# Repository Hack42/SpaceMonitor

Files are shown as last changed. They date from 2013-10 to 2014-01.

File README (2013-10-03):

SpaceMonitor controller

Dit project heeft als doel het beter bewaken van de ruimtes in de space. Momenteel wordt de temperatuur gemonitord, en wordt bewaakt of van een aantal ruimtes de ramen gesloten zijn als de SpaceState uit staat.

Het project voorziet in een controller per ruimte, die serieel communiceert met een centraal systeem. Deze controller is gebaseerd op een ATMEGA88 of 168, en is voorzien van 
* 12 I/O poorten (waarvan maximaal 4 als analoge ingang geschakeld kunnen worden)
* 2 open-collector uitgangen, max. 35V 1A
* een Dallas 18B20 voor temperatuurmeting
* optioneel een MAX232 voor de seriele verbinding, wanneer TTL-nivo RS232 niet voldoet

Ramen en deuren kunnen via microswitches verbonden worden met elk een I/O poort. De overige poorten kunnen gebruikt worden voor andere signaalgevers, of om apparatuur aan te sturen. De OC-uitgangen kunnen gebruikt worden om bijvoorbeeld een sirene of een flitslamp te schakelen

https://hack42.nl/wiki/Space_monitoring

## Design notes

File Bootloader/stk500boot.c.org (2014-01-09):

/*****************************************************************************
Title:     STK500v2 compatible bootloader
Author:    Peter Fleury <pfleury@gmx.ch>   http://jump.to/fleury
File:      $Id: stk500boot.c,v 1.15 2008/05/25 09:09:30 peter Exp $
Compiler:  avr-gcc 4.x / avr-libc 1.4.x 
Hardware:  All AVRs with bootloader support, tested with ATmega8
License:   GNU General Public License 
          
DESCRIPTION:
    This program allows an AVR with bootloader capabilities to 
    read/write its own Flash/EEprom. To enter Programming mode   
    an input pin is checked. If this pin is pulled low, programming mode  
    is entered. If not, normal execution is done from $0000 
    "reset" vector in Application area.
    Size < 500 words, fits into a 512 word bootloader section 
	when compiled with avr-gcc 4.1
   
USAGE:
    - Set AVR MCU type and clock-frequency (F_CPU) in the Makefile.
    - Set baud rate below (AVRISP only works with 115200 bps)
    - compile/link the bootloader with the supplied Makefile
    - program the "Boot Flash section size" (BOOTSZ fuses),
      for boot-size 512 words:  program BOOTSZ1
    - enable the BOOT Reset Vector (program BOOTRST)
    - Upload the hex file to the AVR using any ISP programmer
    - Program Boot Lock Mode 3 (program BootLock 11 and BootLock 12 lock bits)
    - Reset your AVR while keeping PROG_PIN pulled low
    - Start AVRISP Programmer (AVRStudio/Tools/Program AVR)
    - AVRISP will detect the bootloader
    - Program your application FLASH file and optional EEPROM file using AVRISP
    
Note: 
    Erasing the device without flashing, through AVRISP GUI button "Erase Device" 
    is not implemented, due to AVRStudio limitations.
    Flash is always erased before programming.
    
    Normally the bootloader accepts further commands after programming. 
    The bootloader exits and starts applicaton code after programming 
    when ENABLE_LEAVE_BOOTLADER is defined.
    Use Auto Programming mode to programm both flash and eeprom, 
    otherwise bootloader will exit after flash programming.
    
	AVRdude:
	Please uncomment #define REMOVE_CMD_SPI_MULTI when using AVRdude.
	Comment #define REMOVE_PROGRAM_LOCK_BIT_SUPPORT to reduce code size
	Read Fuse Bits and Read/Write Lock Bits is not supported

NOTES:
    Based on Atmel Application Note AVR109 - Self-programming
    Based on Atmel Application Note AVR068 - STK500v2 Protocol    
          
LICENSE:
    Copyright (C) 2006 Peter Fleury

    This program is free software; you can redistribute it and/or modify
    it under the terms of the GNU General Public License as published by
    the Free Software Foundation; either version 2 of the License, or
    any later version.

    This program is distributed in the hope that it will be useful,
    but WITHOUT ANY WARRANTY; without even the implied warranty of
    MERCHANTABILITY or FITNESS FOR A PARTICULAR PURPOSE.  See the
    GNU General Public License for more details.

*****************************************************************************/
#include <inttypes.h>
#include <avr/io.h>
#include <avr/interrupt.h>
#include <avr/boot.h>
#include <avr/pgmspace.h>
#include "command.h"

/*
 * Uncomment the following lines to save code space 
 */
//#define REMOVE_PROGRAM_LOCK_BIT_SUPPORT  // disable program lock bits
//#define REMOVE_BOOTLOADER_LED            // no LED to show active bootloader
//#define REMOVE_PROG_PIN_PULLUP           // disable internal pullup, use external 
#define REMOVE_CMD_SPI_MULTI             // disable processing of SPI_MULTI commands

/*
 *  Uncomment to leave bootloader and jump to application after programming.
 */
//#define ENABLE_LEAVE_BOOTLADER           

/* 
 * Pin "PROG_PIN" on port "PROG_PORT" has to be pulled low
 * (active low) to start the bootloader 
 * uncomment #define REMOVE_PROG_PIN_PULLUP if using an external pullup
 */
#define PROG_PORT  PORTD
#define PROG_DDR   DDRD
#define PROG_IN    PIND
#define PROG_PIN   PIND2

/*
 * Active-low LED on pin "PROGLED_PIN" on port "PROGLED_PORT" 
 * indicates that bootloader is active
 */
#define PROGLED_PORT PORTB
#define PROGLED_DDR  DDRB
#define PROGLED_PIN  PINB1

/*
 * define CPU frequency in Mhz here if not defined in Makefile 
 */
#ifndef F_CPU
#define F_CPU 7372800UL
#endif

/*
 * define which UART channel will be used, if device with two UARTs is used
 */
//#define USE_USART1        // undefined means use USART0

/*
 * UART Baudrate, AVRStudio AVRISP only accepts 115200 bps
 */
#define BAUDRATE 115200

/*
 *  Enable (1) or disable (0) USART double speed operation
 */
#define UART_BAUDRATE_DOUBLE_SPEED 0

/*
 * HW and SW version, reported to AVRISP, must match version of AVRStudio
 */
#define CONFIG_PARAM_BUILD_NUMBER_LOW	0
#define CONFIG_PARAM_BUILD_NUMBER_HIGH	0
#define CONFIG_PARAM_HW_VER				0x0F
#define CONFIG_PARAM_SW_MAJOR			2
#define CONFIG_PARAM_SW_MINOR			0x0A

/*
 * Calculate the address where the bootloader starts from FLASHEND and BOOTSIZE
 * (adjust BOOTSIZE below and BOOTLOADER_ADDRESS in Makefile if you want to change the size of the bootloader)
 */
#define BOOTSIZE 512
#define APP_END  (FLASHEND -(2*BOOTSIZE) + 1)

/*
 * Signature bytes are not available in avr-gcc io_xxx.h
 */
#if defined (__AVR_ATmega8__)
    #define SIGNATURE_BYTES 0x1E9307
#elif defined (__AVR_ATmega16__)
    #define SIGNATURE_BYTES 0x1E9403
#elif defined (__AVR_ATmega32__)
    #define SIGNATURE_BYTES 0x1E9502
#elif defined (__AVR_ATmega8515__)
    #define SIGNATURE_BYTES 0x1E9306
#elif defined (__AVR_ATmega8535__)
    #define SIGNATURE_BYTES 0x1E9308
#elif defined (__AVR_ATmega88__)
    #define SIGNATURE_BYTES 0x1E930A
#elif defined (__AVR_ATmega162__)
    #define SIGNATURE_BYTES 0x1E9404
#elif defined (__AVR_ATmega168__)
    #define SIGNATURE_BYTES 0x1E9406
#elif defined (__AVR_ATmega128__)
    #define SIGNATURE_BYTES 0x1E9702
#elif defined (__AVR_AT90CAN32__)
	#define SIGNATURE_BYTES 0x1E9581
#elif defined (__AVR_AT90CAN64__)
	#define SIGNATURE_BYTES 0x1E9681
#elif defined (__AVR_AT90CAN128__)
	#define SIGNATURE_BYTES 0x1E9781    
#else
	#error "no signature definition for MCU available"
#endif

/*
 *  Defines for the various USART registers
 */
#if  defined(__AVR_ATmega8__)    || defined(__AVR_ATmega16__) || defined(__AVR_ATmega32__) \
  || defined(__AVR_ATmega8515__) || defined(__AVR_ATmega8535__) 
/* 
 * ATMega with one USART
 */ 
#define	UART_BAUD_RATE_LOW	     UBRRL
#define	UART_STATUS_REG	         UCSRA
#define	UART_CONTROL_REG	     UCSRB
#define	UART_ENABLE_TRANSMITTER	 TXEN
#define	UART_ENABLE_RECEIVER	 RXEN
#define	UART_TRANSMIT_COMPLETE	 TXC
#define	UART_RECEIVE_COMPLETE	 RXC
#define	UART_DATA_REG	         UDR
#define UART_DOUBLE_SPEED        U2X

#elif  defined(__AVR_ATmega64__) || defined(__AVR_ATmega128__) || defined(__AVR_ATmega162__) || defined(__AVR_ATmega88__) || defined(__AVR_ATmega168__) \
	|| defined(__AVR_AT90CAN32__) || defined(__AVR_AT90CAN64__) || defined(__AVR_AT90CAN128__)
/* 
 *  ATMega with two USART, select USART for bootloader using USE_USART1 define
 */ 
#ifndef USE_USART1

#define	UART_BAUD_RATE_LOW	     UBRR0L
#ifdef UBRR0H
#define UART_BAUD_RATE_HIGH	     UBRR0H
#endif
#define	UART_STATUS_REG	         UCSR0A
#define	UART_CONTROL_REG	     UCSR0B
#define	UART_ENABLE_TRANSMITTER	 TXEN0
#define	UART_ENABLE_RECEIVER	 RXEN0
#define	UART_TRANSMIT_COMPLETE	 TXC0
#define	UART_RECEIVE_COMPLETE	 RXC0
#define	UART_DATA_REG	         UDR0
#define UART_DOUBLE_SPEED        U2X0

#else

#define	UART_BAUD_RATE_LOW	     UBRR1L
#ifdef UBRR1H
#define UART_BAUD_RATE_HIGH      UBRR1H
#endif
#define	UART_STATUS_REG	         UCSR1A
#define	UART_CONTROL_REG	     UCSR1B
#define	UART_ENABLE_TRANSMITTER	 TXEN1
#define	UART_ENABLE_RECEIVER	 RXEN1
#define	UART_TRANSMIT_COMPLETE	 TXC1
#define	UART_RECEIVE_COMPLETE	 RXC1
#define	UART_DATA_REG	         UDR1
#define UART_DOUBLE_SPEED        U2X1

#endif

#else
	#error "no UART definition for MCU available"
#endif

/*
 * Macros to map the new ATmega88/168 EEPROM bits
 */
#ifdef EEMPE        				        		            
#define EEMWE EEMPE
#define EEWE  EEPE
#endif

/*
 * Macro to calculate UBBR from XTAL and baudrate
 */
#if UART_BAUDRATE_DOUBLE_SPEED
#define UART_BAUD_SELECT(baudRate,xtalCpu) (((float)(xtalCpu))/(((float)(baudRate))*8.0)-1.0+0.5)
#else
#define UART_BAUD_SELECT(baudRate,xtalCpu) (((float)(xtalCpu))/(((float)(baudRate))*16.0)-1.0+0.5)
#endif

/*
 * States used in the receive state machine
 */
#define	ST_START		0
#define	ST_GET_SEQ_NUM	1
#define ST_MSG_SIZE_1	2
#define ST_MSG_SIZE_2	3
#define ST_GET_TOKEN	4
#define ST_GET_DATA		5
#define	ST_GET_CHECK	6
#define	ST_PROCESS		7

/*
 * use 16bit address variable for ATmegas with <= 64K flash
 */
#if defined(RAMPZ)
typedef uint32_t address_t;
#else
typedef uint16_t address_t;
#endif

/*
 * function prototypes
 */ 
static void sendchar(char c);
static unsigned char recchar(void);

/*
 * since this bootloader is not linked against the avr-gcc crt1 functions,
 * to reduce the code size, we need to provide our own initialization
 */
void __jumpMain     (void) __attribute__ ((naked)) __attribute__ ((section (".init9")));

void __jumpMain(void)
{    
    asm volatile ( ".set __stack, %0" :: "i" (RAMEND) );
    
    /* init stack here, bug WinAVR 20071221 does not init stack based on __stack */  
    asm volatile ("ldi r24,%0":: "M" (RAMEND & 0xFF));          
    asm volatile ("ldi r25,%0":: "M" (RAMEND >> 8));
    asm volatile ("out __SP_H__,r25" ::);
    asm volatile ("out __SP_L__,r24" ::);
    
    asm volatile ( "clr __zero_reg__" );                       // GCC depends on register r1 set to 0
    asm volatile ( "out %0, __zero_reg__" :: "I" (_SFR_IO_ADDR(SREG)) );  // set SREG to 0
#ifndef REMOVE_PROG_PIN_PULLUP	 
	PROG_PORT |= (1<<PROG_PIN);		                           // Enable internal pullup
#endif    
    asm volatile ( "rjmp main");                               // jump to main()
}

/*
 * send single byte to USART, wait until transmission is completed
 */
static void sendchar(char c)
{
    UART_DATA_REG = c;                                         // prepare transmission
    while (!(UART_STATUS_REG & (1 << UART_TRANSMIT_COMPLETE)));// wait until byte sent
    UART_STATUS_REG |= (1 << UART_TRANSMIT_COMPLETE);          // delete TXCflag
}

/*
 * Read single byte from USART, block if no data available
 */
static unsigned char recchar(void)
{
    while(!(UART_STATUS_REG & (1 << UART_RECEIVE_COMPLETE)));  // wait for data
    return UART_DATA_REG;
}

int main(void) __attribute__ ((OS_main));
int main(void)
{
    address_t       address = 0;
    address_t       eraseAddress = 0;	
	unsigned char   msgParseState;
    unsigned int    i = 0;
    unsigned char   checksum = 0;
    unsigned char   seqNum = 0;
    unsigned int    msgLength = 0;
    unsigned char   msgBuffer[285];
    unsigned char   c, *p;
    unsigned char   isLeave = 0;

	/*
	 * Branch to bootloader or application code ?
	 */	
	if(!(PROG_IN & (1<<PROG_PIN)))  
	{ 	    
#ifndef REMOVE_BOOTLOADER_LED
        /* PROG_PIN pulled low, indicate with LED that bootloader is active */
        PROGLED_DDR  |= (1<<PROGLED_PIN);
        PROGLED_PORT &= ~(1<<PROGLED_PIN);
#endif
        /*
         * Init UART
         * set baudrate and enable USART receiver and transmiter without interrupts 
         */     
#if UART_BAUDRATE_DOUBLE_SPEED
        UART_STATUS_REG   |=  (1 <<UART_DOUBLE_SPEED);
#endif
  
#ifdef UART_BAUD_RATE_HIGH    
        UART_BAUD_RATE_HIGH = 0;     
#endif       
        UART_BAUD_RATE_LOW = UART_BAUD_SELECT(BAUDRATE,F_CPU);
        UART_CONTROL_REG   = (1 << UART_ENABLE_RECEIVER) | (1 << UART_ENABLE_TRANSMITTER); 

        /* main loop */
        while(!isLeave)                             
        {   
            /*
             * Collect received bytes to a complete message
             */            
            msgParseState = ST_START;
	        while ( msgParseState != ST_PROCESS )
	        {
           		c = recchar();
                switch (msgParseState)
                {
                case ST_START:
				    if( c == MESSAGE_START )
				    {
					    msgParseState = ST_GET_SEQ_NUM;
					    checksum = MESSAGE_START^0;
				    }
				    break;
				    
				case ST_GET_SEQ_NUM:
                    if ( (c == 1) || (c == seqNum) )
                    {
				        seqNum = c;
				        msgParseState = ST_MSG_SIZE_1;
				        checksum ^= c;
                    }
                    else
                    {
                        msgParseState = ST_START;
                    }
			        break;
			        
			    case ST_MSG_SIZE_1:			    
				    msgLength = (unsigned int)c<<8;
				    msgParseState = ST_MSG_SIZE_2;
				    checksum ^= c;
				    break;
				    
			    case ST_MSG_SIZE_2:			
				    msgLength |= c;
				    msgParseState = ST_GET_TOKEN;
				    checksum ^= c;
				    break;
			    
			    case ST_GET_TOKEN:
			        if ( c == TOKEN )
				    {
					    msgParseState = ST_GET_DATA;
					    checksum ^= c;
					    i = 0;
				    }
				    else
				    {
				        msgParseState = ST_START;
				    }
				    break;
			    
			    case ST_GET_DATA:			        
				    msgBuffer[i++] = c;
				    checksum ^= c;
				    if ( i == msgLength )
				    {
					    msgParseState = ST_GET_CHECK;
				    }
				    break;
						
			    case ST_GET_CHECK:
				    if( c == checksum )
				    {
					    msgParseState = ST_PROCESS;					    
				    }
				    else
				    {
				        msgParseState = ST_START;
				    }
				    break;
				}//switch
			}//while(msgParseState)
			
			/*
			 * Now process the STK500 commands, see Atmel Appnote AVR068
			 */
			
	        switch (msgBuffer[0])
	        {
#ifndef REMOVE_CMD_SPI_MULTI
			case CMD_SPI_MULTI:
				{
	                unsigned char answerByte = 0;

                    // only Read Signature Bytes implemented, return dummy value for other instructions
					if ( msgBuffer[4]== 0x30 )
					{						
						unsigned char signatureIndex = msgBuffer[6];						

						if ( signatureIndex == 0 )
							answerByte = (SIGNATURE_BYTES >>16) & 0x000000FF;
						else if ( signatureIndex == 1 )
							answerByte = (SIGNATURE_BYTES >> 8) & 0x000000FF;
						else
							answerByte = SIGNATURE_BYTES & 0x000000FF;
					}					
    				msgLength = 7;
					msgBuffer[1] = STATUS_CMD_OK;
					msgBuffer[2] = 0;					
					msgBuffer[3] = msgBuffer[4];  // Instruction Byte 1
					msgBuffer[4] = msgBuffer[5];  // Instruction Byte 2
					msgBuffer[5] = answerByte;	                
					msgBuffer[6] = STATUS_CMD_OK;
				}
				break;
#endif
            case CMD_SIGN_ON:
		        msgLength = 11;		        
		        msgBuffer[1]  = STATUS_CMD_OK;
		        msgBuffer[2]  = 8;
		        msgBuffer[3]  = 'A';
		        msgBuffer[4]  = 'V';
		        msgBuffer[5]  = 'R';
		        msgBuffer[6]  = 'I';
		        msgBuffer[7]  = 'S';
		        msgBuffer[8]  = 'P';
		        msgBuffer[9]  = '_';
		        msgBuffer[10] = '2';
		        break;
	        
	        case CMD_GET_PARAMETER:
	            {
	                unsigned char value;
	                
    		        switch(msgBuffer[1])
    		        {
    			    case PARAM_BUILD_NUMBER_LOW:
    				    value = CONFIG_PARAM_BUILD_NUMBER_LOW;
    				    break;				    
    			    case PARAM_BUILD_NUMBER_HIGH:
    				    value = CONFIG_PARAM_BUILD_NUMBER_HIGH;
    				    break;				    
    			    case PARAM_HW_VER:
    				    value = CONFIG_PARAM_HW_VER;
    				    break;				    
    			    case PARAM_SW_MAJOR:
    				    value = CONFIG_PARAM_SW_MAJOR;
    				    break;
    			    case PARAM_SW_MINOR:
    				    value = CONFIG_PARAM_SW_MINOR;
    				    break;				
    				default:
    				    value = 0;
    				    break;
    		        }
		            msgLength = 3;		        
		            msgBuffer[1] = STATUS_CMD_OK;
		            msgBuffer[2] = value;
		        }
	            break;
	            
	        case CMD_LEAVE_PROGMODE_ISP:
#ifdef ENABLE_LEAVE_BOOTLADER
	            isLeave = 1;
#endif
	        case CMD_ENTER_PROGMODE_ISP:    	            
	        case CMD_SET_PARAMETER:	        
		        msgLength = 2;		        
		        msgBuffer[1] = STATUS_CMD_OK;
                break;

            case CMD_READ_SIGNATURE_ISP:
                {
                    unsigned char signatureIndex = msgBuffer[4];
                    unsigned char signature;

                    if ( signatureIndex == 0 )
                        signature = (SIGNATURE_BYTES >>16) & 0x000000FF;
                    else if ( signatureIndex == 1 )
                        signature = (SIGNATURE_BYTES >> 8) & 0x000000FF;
                    else
                        signature = SIGNATURE_BYTES & 0x000000FF;

	                msgLength = 4;
	                msgBuffer[1] = STATUS_CMD_OK;
	                msgBuffer[2] = signature;
	                msgBuffer[3] = STATUS_CMD_OK;	                
	            }
                break;

            case CMD_READ_LOCK_ISP:            
                msgLength = 4;
	            msgBuffer[1] = STATUS_CMD_OK;
	            msgBuffer[2] = boot_lock_fuse_bits_get( GET_LOCK_BITS );
	            msgBuffer[3] = STATUS_CMD_OK;	                                                
                break;
            
            case CMD_READ_FUSE_ISP:
                {                    
                    unsigned char fuseBits;                    
                    
                    if ( msgBuffer[2] == 0x50 )
                    {
                        if ( msgBuffer[3] == 0x08 )
                            fuseBits = boot_lock_fuse_bits_get( GET_EXTENDED_FUSE_BITS );                            
                        else
                            fuseBits = boot_lock_fuse_bits_get( GET_LOW_FUSE_BITS );                            
                    }
                    else 
                    {
                        fuseBits = boot_lock_fuse_bits_get( GET_HIGH_FUSE_BITS );
                    }                    
                    msgLength = 4;    
	                msgBuffer[1] = STATUS_CMD_OK;
	                msgBuffer[2] = fuseBits;	                
	                msgBuffer[3] = STATUS_CMD_OK;	                                    
                }
                break;
                
#ifndef REMOVE_PROGRAM_LOCK_BIT_SUPPORT
            case CMD_PROGRAM_LOCK_ISP:
                {
                    unsigned char lockBits = msgBuffer[4];
                    
                    lockBits = (~lockBits) & 0x3C;  // mask BLBxx bits
				    boot_lock_bits_set(lockBits);	// and program it
				    boot_spm_busy_wait();
                    
                    msgLength = 3;
	                msgBuffer[1] = STATUS_CMD_OK;	                
	                msgBuffer[2] = STATUS_CMD_OK;	                                                        
                }
                break;
#endif
            case CMD_CHIP_ERASE_ISP:
                eraseAddress = 0;
	            msgLength = 2;
	            msgBuffer[1] = STATUS_CMD_OK;
                break;

            case CMD_LOAD_ADDRESS:
#if defined(RAMPZ)
                address = ( ((address_t)(msgBuffer[1])<<24)|((address_t)(msgBuffer[2])<<16)|((address_t)(msgBuffer[3])<<8)|(msgBuffer[4]) )<<1;
#else
		        address = ( ((msgBuffer[3])<<8)|(msgBuffer[4]) )<<1;  //convert word to byte address
#endif
		        msgLength = 2;
		        msgBuffer[1] = STATUS_CMD_OK;
                break;
                
            case CMD_PROGRAM_FLASH_ISP:
            case CMD_PROGRAM_EEPROM_ISP:                
                {
                    unsigned int  size = (((unsigned int)msgBuffer[1])<<8) | msgBuffer[2];
                    unsigned char *p = msgBuffer+10;
                    unsigned int  data;
                    unsigned char highByte, lowByte;                    
                    address_t     tempaddress = address;

                    if ( msgBuffer[0] == CMD_PROGRAM_FLASH_ISP )
                    {
                		// erase only main section (bootloader protection)
                		if  (  eraseAddress < APP_END )
                		{
                			boot_page_erase(eraseAddress);	// Perform page erase
                			boot_spm_busy_wait();		// Wait until the memory is erased.
                			eraseAddress += SPM_PAGESIZE;    // point to next page to be erase
                		}
                        
    		            /* Write FLASH */
        		        do {
        		            lowByte   = *p++;
        		            highByte  = *p++;
        				    
        				    data =  (highByte << 8) | lowByte;
        				    boot_page_fill(address,data);
        											
        				    address = address + 2;  	// Select next word in memory
        				    size -= 2;			// Reduce number of bytes to write by two    
        			    } while(size);			// Loop until all bytes written
        			    
            			boot_page_write(tempaddress);
        	    		boot_spm_busy_wait();	
        		    	boot_rww_enable();				// Re-enable the RWW section                    
    		        }
    		        else
    		        {
    		            /* write EEPROM */
        			    do {
        	 	            EEARL = address;			// Setup EEPROM address
        	                EEARH = (address >> 8);
        				    address++;					// Select next EEPROM byte
        
        				    EEDR= *p++;				    // get byte from buffer
        	                EECR |= (1<<EEMWE);			// Write data into EEPROM
        	                EECR |= (1<<EEWE);
        	            
        				    while (EECR & (1<<EEWE));	// Wait for write operation to finish
        				    size--;						// Decrease number of bytes to write
        			    } while(size);					// Loop until all bytes written    		            
    		        }
           		    msgLength = 2;
		            msgBuffer[1] = STATUS_CMD_OK;    		        
                }
                break;
                
            case CMD_READ_FLASH_ISP:
            case CMD_READ_EEPROM_ISP:                                                
                {
                    unsigned int  size = (((unsigned int)msgBuffer[1])<<8) | msgBuffer[2];
                    unsigned char *p = msgBuffer+1;
                    msgLength = size+3;
                    
                    *p++ = STATUS_CMD_OK;                    
                    if (msgBuffer[0] == CMD_READ_FLASH_ISP )
                    {
                        unsigned int data;
                        
                        // Read FLASH
                        do {                            
#if defined(RAMPZ)
                			data = pgm_read_word_far(address);
#else
        		        	data = pgm_read_word_near(address);
#endif
        			        *p++ = (unsigned char)data;         //LSB
        			        *p++ = (unsigned char)(data >> 8);	//MSB  
        			        address    += 2;  	 // Select next word in memory
        			        size -= 2;
                        }while (size);
                    }
                    else
                    {
          			    /* Read EEPROM */
        			    do {
        			        EEARL = address;			// Setup EEPROM address
        			        EEARH = ((address >> 8));
        			        address++;					// Select next EEPROM byte
        			        EECR |= (1<<EERE);			// Read EEPROM
        			        *p++ = EEDR;				// Send EEPROM data
        			        size--;    			        
        		        }while(size);
                    }
                    *p++ = STATUS_CMD_OK;
                }
                break;

	        default:
	            msgLength = 2;   
	            msgBuffer[1] = STATUS_CMD_FAILED;
	            break;
	        }

            /*
             * Now send answer message back
             */
	        sendchar(MESSAGE_START);     
	        checksum = MESSAGE_START^0;
	        
	        sendchar(seqNum);
	        checksum ^= seqNum;
	        
	        c = ((msgLength>>8)&0xFF);
	        sendchar(c);
	        checksum ^= c;
	        
	        c = msgLength&0x00FF;
	        sendchar(c);
	        checksum ^= c;
	        
	        sendchar(TOKEN);
	        checksum ^= TOKEN;

            p = msgBuffer;
            while ( msgLength )
            {                
               c = *p++;
               sendchar(c);
               checksum ^=c;
               msgLength--;               
            }                   
	        sendchar(checksum);	        
	        seqNum++;

	    }//for

#ifndef REMOVE_BOOTLOADER_LED
        PROGLED_DDR  &= ~(1<<PROGLED_PIN);   // set to default     
#endif
    }
    
	/*
	 * Now leave bootloader
	 */
#ifndef REMOVE_PROG_PIN_PULLUP	
	PROG_PORT &= ~(1<<PROG_PIN);    // set to default
#endif	
	boot_rww_enable();              // enable application section
	
	// Jump to Reset vector in Application Section
	// (clear register, push this register to the stack twice = adress 0x0000/words, and return to this address) 
    asm volatile ( 
		"clr r1" "\n\t"
		"push r1" "\n\t"
        "push r1" "\n\t" 
        "ret"     "\n\t" 
    ::); 

     /*
     * Never return to stop GCC to generate exit return code
     * Actually we will never reach this point, but the compiler doesn't 
     * understand this
     */
    for(;;);
}

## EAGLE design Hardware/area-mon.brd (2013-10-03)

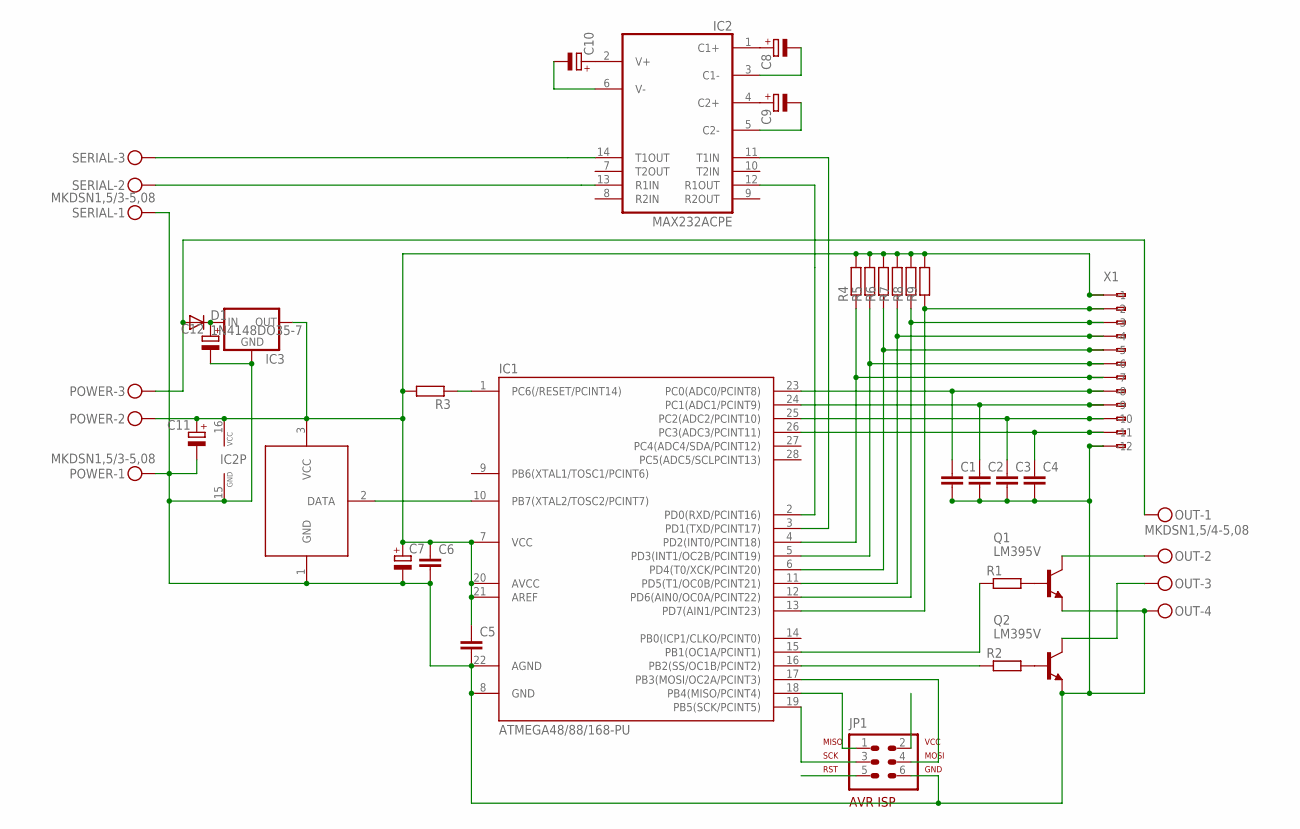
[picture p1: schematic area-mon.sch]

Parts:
C1, C2, C3, C4, C5, C6: C-EU050-024X044; C050-024X044
C7: CPOL-EUE5-8.5; E5-8,5
C8, C9, C10, C11, C12: CPOL-EUE2.5-5; E2,5-5
D1: 1N4148DO35-7; DO35-7
IC1: ATMEGA48/88/168-PU; DIL28-3
IC2: MAX232ACPE; DIL16
IC3: 78XXTO92L; TO92L
JP1: AVR-ISP-6VERT; AVR-ISP-6
OUT: MKDSN1,5/4-5,08
POWER: MKDSN1,5/3-5,08
Q1, Q2: LM395V; TO220V
R1, R2, R3, R4, R5, R6, R7, R8, R9: R-EU0207/10; 0207/10
SERIAL: MKDSN1,5/3-5,08
U$4: DS18B20; TO92-
X1: 233-512; MPN 0233-0512

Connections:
1WIRE: IC1.10 (PB7(XTAL2/TOSC2/PCINT7)), U$4.2 (DATA)
GND: C1.2, C2.2, C3.2, C4.2, C5.2, C6.2, C7.-, C11.-, C12.-, IC1.8 (GND), IC1.22 (AGND), IC2.15 (GND), IC3.2 (GND), JP1.6, OUT.4, POWER.1, Q1.C (E), Q2.C (E), SERIAL.1, U$4.1 (GND), X1.A12 (-12), X1.B12 (B-12)
MISO: IC1.18 (PB4(MISO/PCINT4)), JP1.1
MON-A-1: C1.1, IC1.23 (PC0(ADC0/PCINT8)), X1.A8 (-8), X1.B8 (B-8)
MON-A-2: C2.1, IC1.24 (PC1(ADC1/PCINT9)), X1.A9 (-9), X1.B9 (B-9)
MON-A-3: C3.1, IC1.25 (PC2(ADC2/PCINT10)), X1.A10 (-10), X1.B10 (B-10)
MON-A-4: C4.1, IC1.26 (PC3(ADC3/PCINT11)), X1.A11 (-11), X1.B11 (B-11)
MON-D-1: IC1.13 (PD7(AIN1/PCINT23)), R9.1, X1.A2 (-2), X1.B2 (B-2)
MON-D-2: IC1.12 (PD6(AIN0/OC0A/PCINT22)), R8.1, X1.A3 (-3), X1.B3 (B-3)
MON-D-3: IC1.11 (PD5(T1/OC0B/PCINT21)), R7.1, X1.A4 (-4), X1.B4 (B-4)
MON-D-4: IC1.6 (PD4(T0/XCK/PCINT20)), R6.1, X1.A5 (-5), X1.B5 (B-5)
MON-D-5: IC1.5 (PD3(INT1/OC2B/PCINT19)), R5.1, X1.A6 (-6), X1.B6 (B-6)
MON-D-6: IC1.4 (PD2(INT0/PCINT18)), R4.1, X1.A7 (-7), X1.B7 (B-7)
MOSI: IC1.17 (PB3(MOSI/OC2A/PCINT3)), JP1.4
unnamed: Q1.B, R1.2
unnamed: Q2.B, R2.2
unnamed: D1.A, OUT.1, POWER.3
unnamed: OUT.2, Q1.E (C)
unnamed: OUT.3, Q2.E (C)
unnamed: C8.+, IC2.1 (C1+)
unnamed: C9.+, IC2.4 (C2+)
unnamed: C9.-, IC2.5 (C2-)
unnamed: C8.-, IC2.3 (C1-)
unnamed: C10.+, IC2.2 (V+)
unnamed: C10.-, IC2.6 (V-)
unnamed: C12.+, D1.C, IC3.1 (IN)
OUT-CH-1: IC1.15 (PB1(OC1A/PCINT1)), R1.1
OUT-CH-2: IC1.16 (PB2(SS/OC1B/PCINT2)), R2.1
RST: IC1.1 (PC6(/RESET/PCINT14)), JP1.5, R3.1
RX-232: IC2.13 (R1IN), SERIAL.2
RXD: IC1.2 (PD0(RXD/PCINT16)), IC2.12 (R1OUT)
SCK: IC1.19 (PB5(SCK/PCINT5)), JP1.3
TX-232: IC2.14 (T1OUT), SERIAL.3
TXD: IC1.3 (PD1(TXD/PCINT17)), IC2.11 (T1IN)
VCC: C5.1, C6.1, C7.+, C11.+, IC1.7 (VCC), IC1.20 (AVCC), IC1.21 (AREF), IC2.16 (VCC), IC3.3 (OUT), JP1.2, POWER.2, R3.2, R4.2, R5.2, R6.2, R7.2, R8.2, R9.2, U$4.3 (VCC), X1.A1 (-1), X1.B1 (B-1)

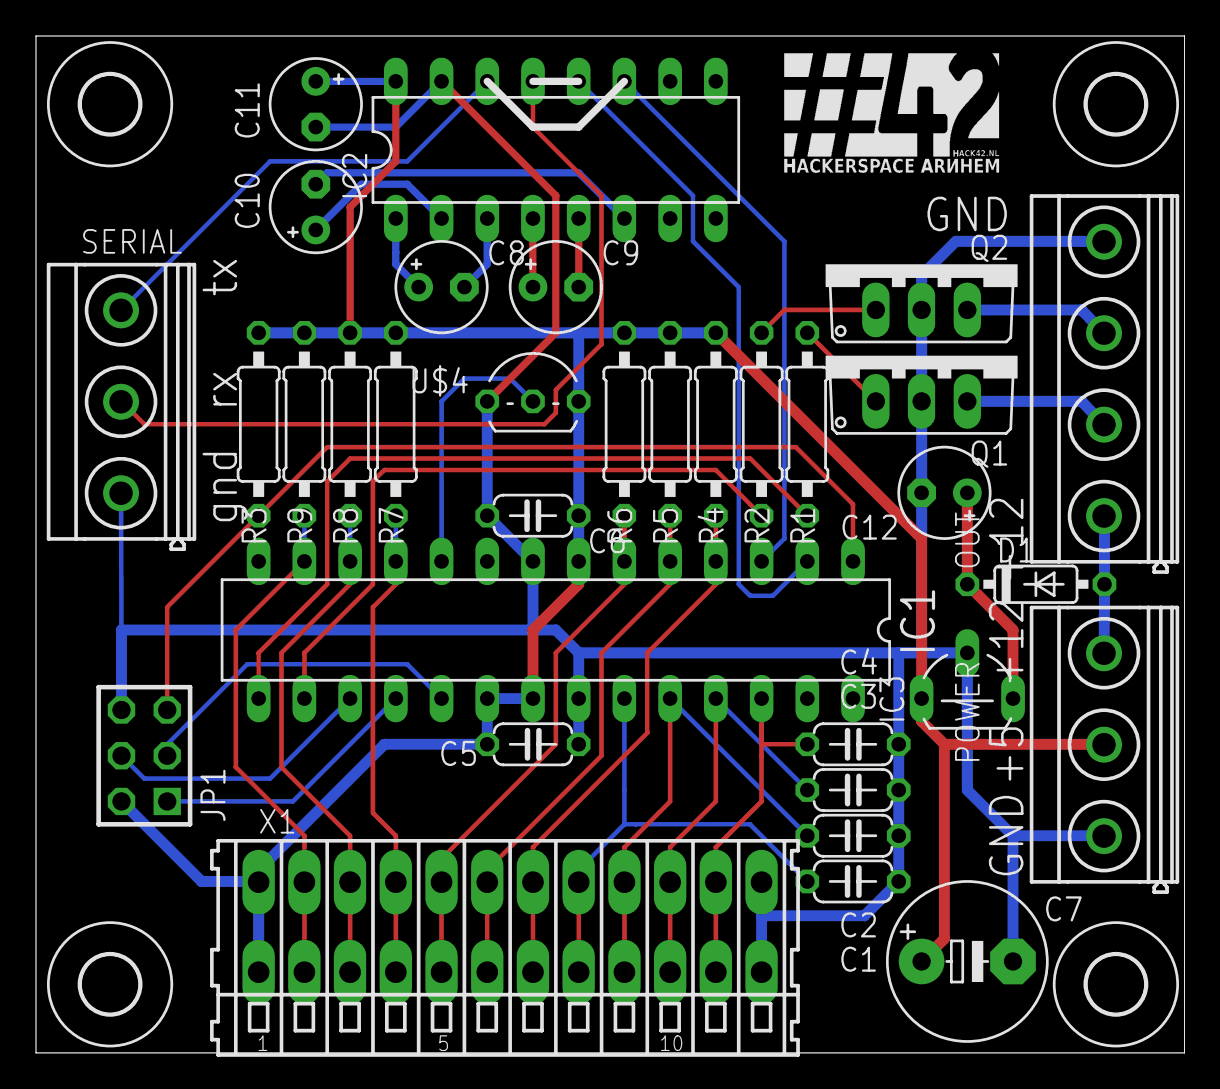
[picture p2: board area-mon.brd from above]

Board: 2 copper layers, 63.8 x 56.5 mm, 38 parts (0 on the bottom side), 35 nets.

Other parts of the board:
U$1, U$2, U$3, U$5: 3,2
U$6: LOGO_HACK42-12X7

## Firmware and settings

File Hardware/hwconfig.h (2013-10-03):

#ifndef HWCONFIG_H
#define HWCONFIG_H

//-----------------------------------------------------------------
//------------------------- DO NOT MODIFY -------------------------
//------------------Generated with the generate_hearer.ulp---------
//-----------------------------------------------------------------


#define 1WIRE_PORT   PORTB
#define 1WIRE_PINREG PINB
#define 1WIRE_PIN    7
#define 1WIRE_DDR    DDRB
#define 1WIRE        B,7

#define MISO_PORT   PORTB
#define MISO_PINREG PINB
#define MISO_PIN    4
#define MISO_DDR    DDRB
#define MISO        B,4

#define MON-A-1_PORT   PORTC
#define MON-A-1_PINREG PINC
#define MON-A-1_PIN    0
#define MON-A-1_DDR    DDRC
#define MON-A-1        C,0

#define MON-A-2_PORT   PORTC
#define MON-A-2_PINREG PINC
#define MON-A-2_PIN    1
#define MON-A-2_DDR    DDRC
#define MON-A-2        C,1

#define MON-A-3_PORT   PORTC
#define MON-A-3_PINREG PINC
#define MON-A-3_PIN    2
#define MON-A-3_DDR    DDRC
#define MON-A-3        C,2

#define MON-A-4_PORT   PORTC
#define MON-A-4_PINREG PINC
#define MON-A-4_PIN    3
#define MON-A-4_DDR    DDRC
#define MON-A-4        C,3

#define MON-D-1_PORT   PORTD
#define MON-D-1_PINREG PIND
#define MON-D-1_PIN    7
#define MON-D-1_DDR    DDRD
#define MON-D-1        D,7

#define MON-D-2_PORT   PORTD
#define MON-D-2_PINREG PIND
#define MON-D-2_PIN    6
#define MON-D-2_DDR    DDRD
#define MON-D-2        D,6

#define MON-D-3_PORT   PORTD
#define MON-D-3_PINREG PIND
#define MON-D-3_PIN    5
#define MON-D-3_DDR    DDRD
#define MON-D-3        D,5

#define MON-D-4_PORT   PORTD
#define MON-D-4_PINREG PIND
#define MON-D-4_PIN    4
#define MON-D-4_DDR    DDRD
#define MON-D-4        D,4

#define MON-D-5_PORT   PORTD
#define MON-D-5_PINREG PIND
#define MON-D-5_PIN    3
#define MON-D-5_DDR    DDRD
#define MON-D-5        D,3

#define MON-D-6_PORT   PORTD
#define MON-D-6_PINREG PIND
#define MON-D-6_PIN    2
#define MON-D-6_DDR    DDRD
#define MON-D-6        D,2

#define MOSI_PORT   PORTB
#define MOSI_PINREG PINB
#define MOSI_PIN    3
#define MOSI_DDR    DDRB
#define MOSI        B,3

#define OUT-CH-1_PORT   PORTB
#define OUT-CH-1_PINREG PINB
#define OUT-CH-1_PIN    1
#define OUT-CH-1_DDR    DDRB
#define OUT-CH-1        B,1

#define OUT-CH-2_PORT   PORTB
#define OUT-CH-2_PINREG PINB
#define OUT-CH-2_PIN    2
#define OUT-CH-2_DDR    DDRB
#define OUT-CH-2        B,2

#define RST_PORT   PORTC
#define RST_PINREG PINC
#define RST_PIN    6
#define RST_DDR    DDRC
#define RST        C,6

#define RXD_PORT   PORTD
#define RXD_PINREG PIND
#define RXD_PIN    0
#define RXD_DDR    DDRD
#define RXD        D,0

#define SCK_PORT   PORTB
#define SCK_PINREG PINB
#define SCK_PIN    5
#define SCK_DDR    DDRB
#define SCK        B,5

#define TXD_PORT   PORTD
#define TXD_PINREG PIND
#define TXD_PIN    1
#define TXD_DDR    DDRD
#define TXD        D,1

#endif //#define HWCONFIG_H
